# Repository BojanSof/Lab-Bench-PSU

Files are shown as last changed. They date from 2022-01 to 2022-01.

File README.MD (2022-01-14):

# Programmable laboratory bench power supply

Programmable laboratory bench PSU, consisting of linear regulator and switching
preregulator.

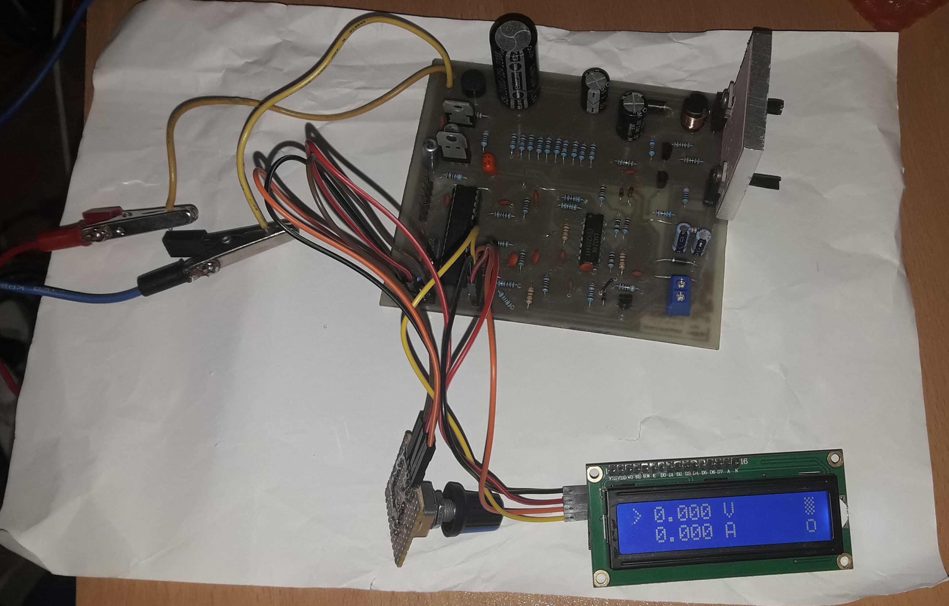
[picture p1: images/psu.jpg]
lab bench psu


## Block diagram

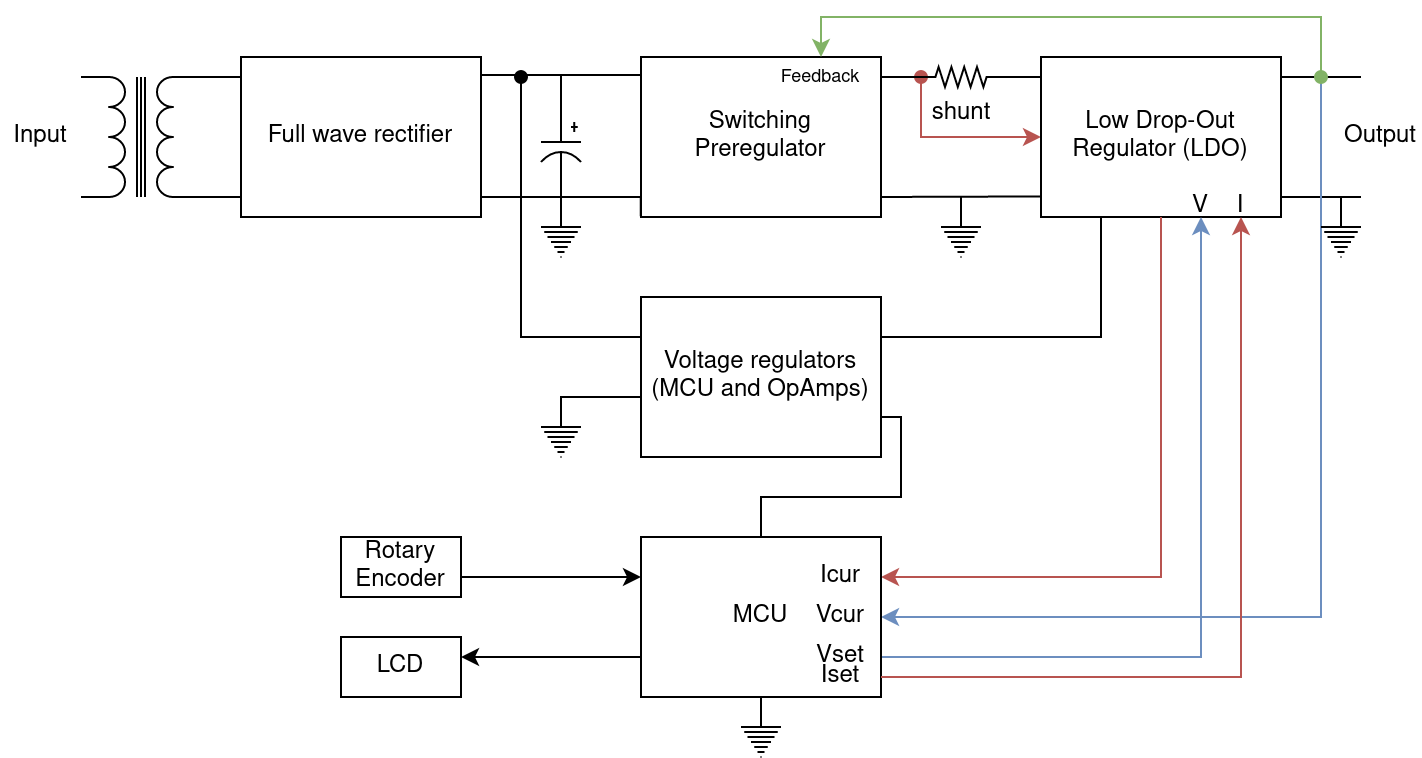
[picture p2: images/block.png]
block diagram


I used transformer just because I had it laying around.

The switching preregulator is actually buck converter realised with LM2576-ADJ
and it keeps constant 1.5 V on the LDO.

The MCU I used is PIC16F18855, which is very easily available in my country and
it is pretty cheap. It has 10-bit ADC and maximum PWM resolution of 10 bits.

The MCU samples the output, divided by 3 with voltage divider, to obtain the
output voltage value, and the output from the differential amplifier whose 
output is proportional to the voltage of the shunt resistor.

The LDO is realised with TIP41 pass transistor and LM324 operational amplifier
among the main components.

The LCD is 2 rows by 16 columns, with HD44780 controller and the interface to 
the MCU is done via I2C I/O expander (PCF8574).

## Goal specifications

Voltage: 0 - 15 V, with steps of 15 mV
Current: 0 - 1 A, with steps of 5 mA

Additional software modifications and testing is required to meet these 
specifications, especially the current limit one.

## PCB and schematic

The schematic and PCB design is created in KiCad.

The PCB is single layer because I made it in my home. I only used THT
components for the whole design.

## Firmware

The firmware is developed using MPLAB X IDE, with the free version of the XC8 
compiler.

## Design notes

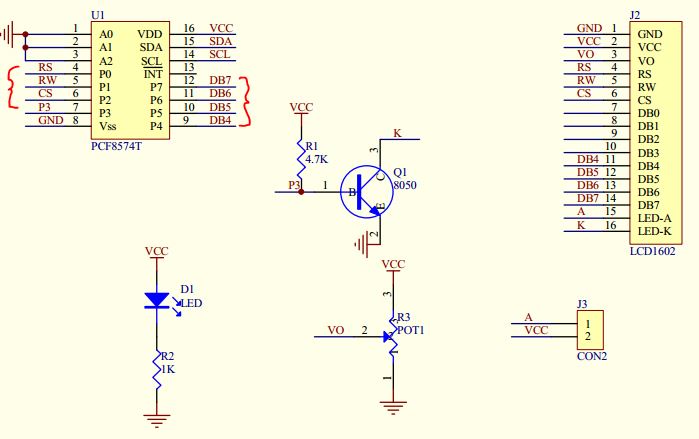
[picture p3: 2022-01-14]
datasheets/lcd_i2c.jpg

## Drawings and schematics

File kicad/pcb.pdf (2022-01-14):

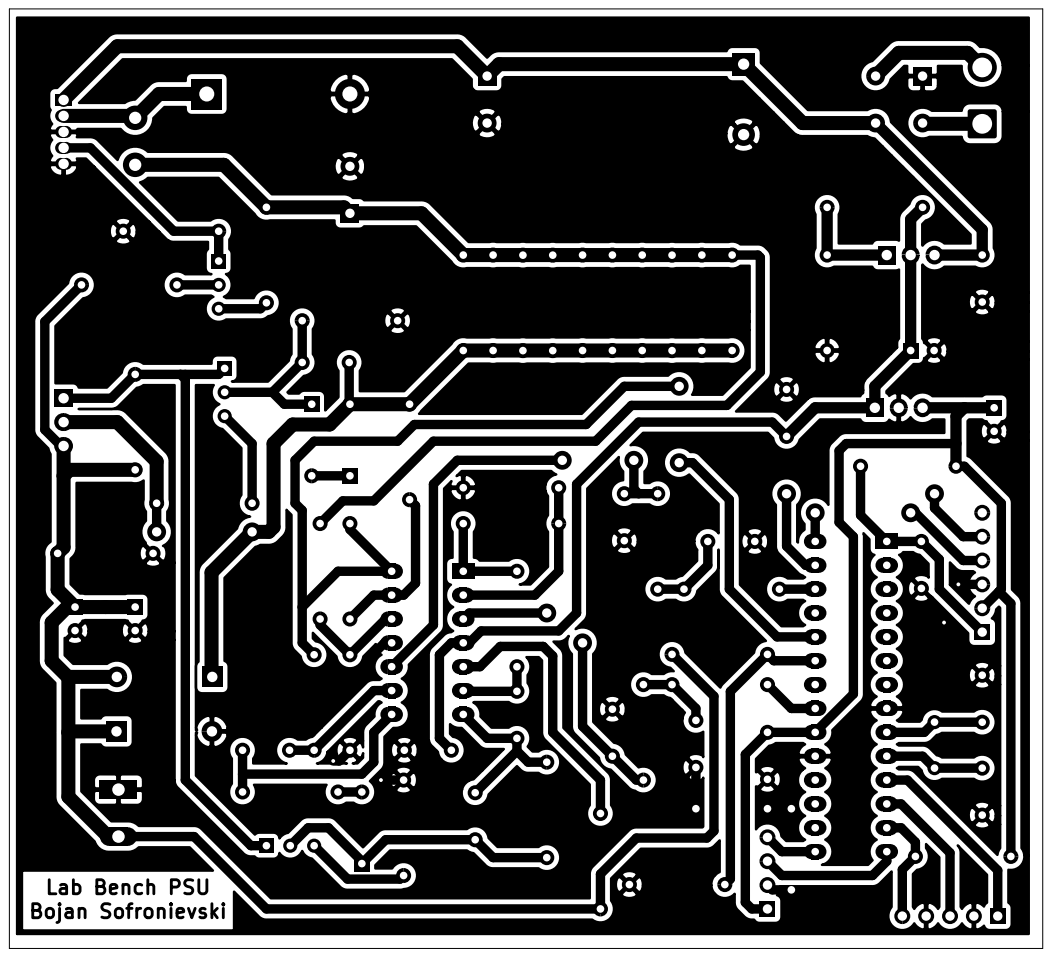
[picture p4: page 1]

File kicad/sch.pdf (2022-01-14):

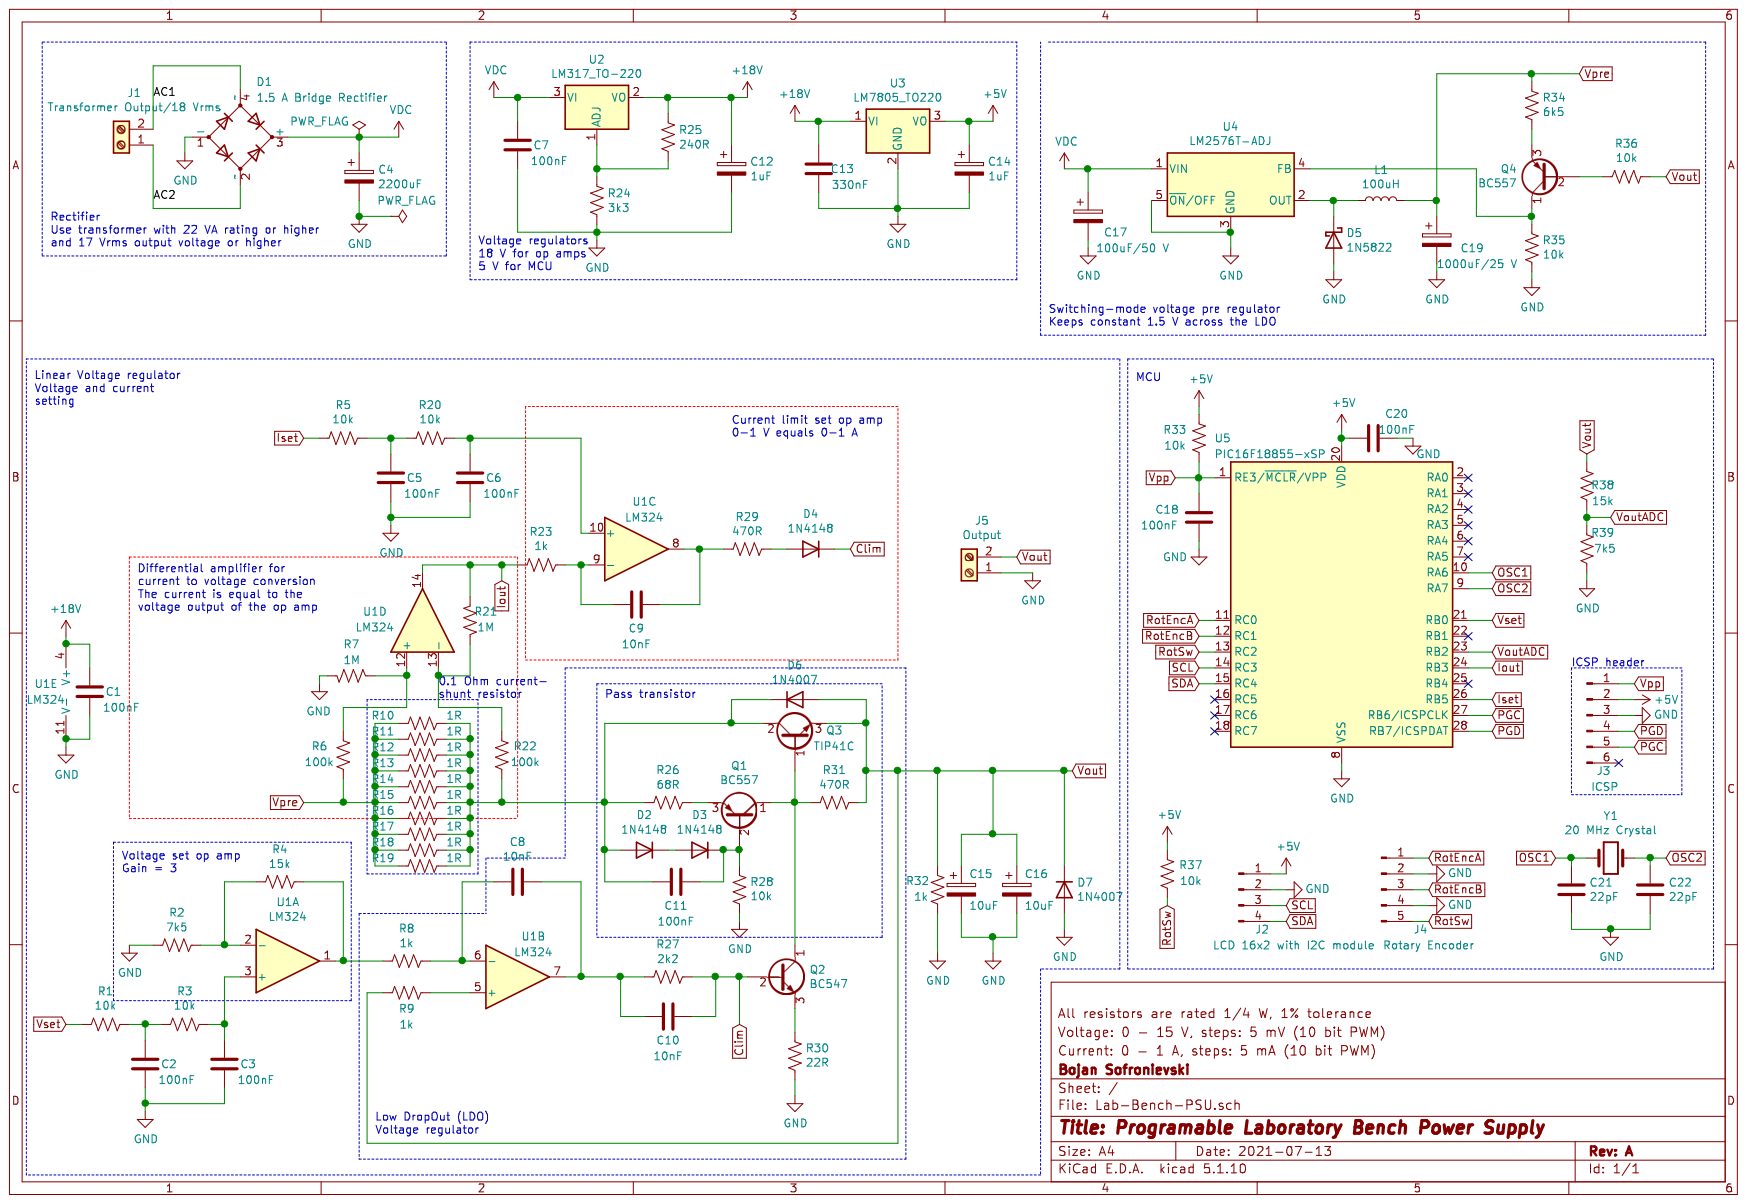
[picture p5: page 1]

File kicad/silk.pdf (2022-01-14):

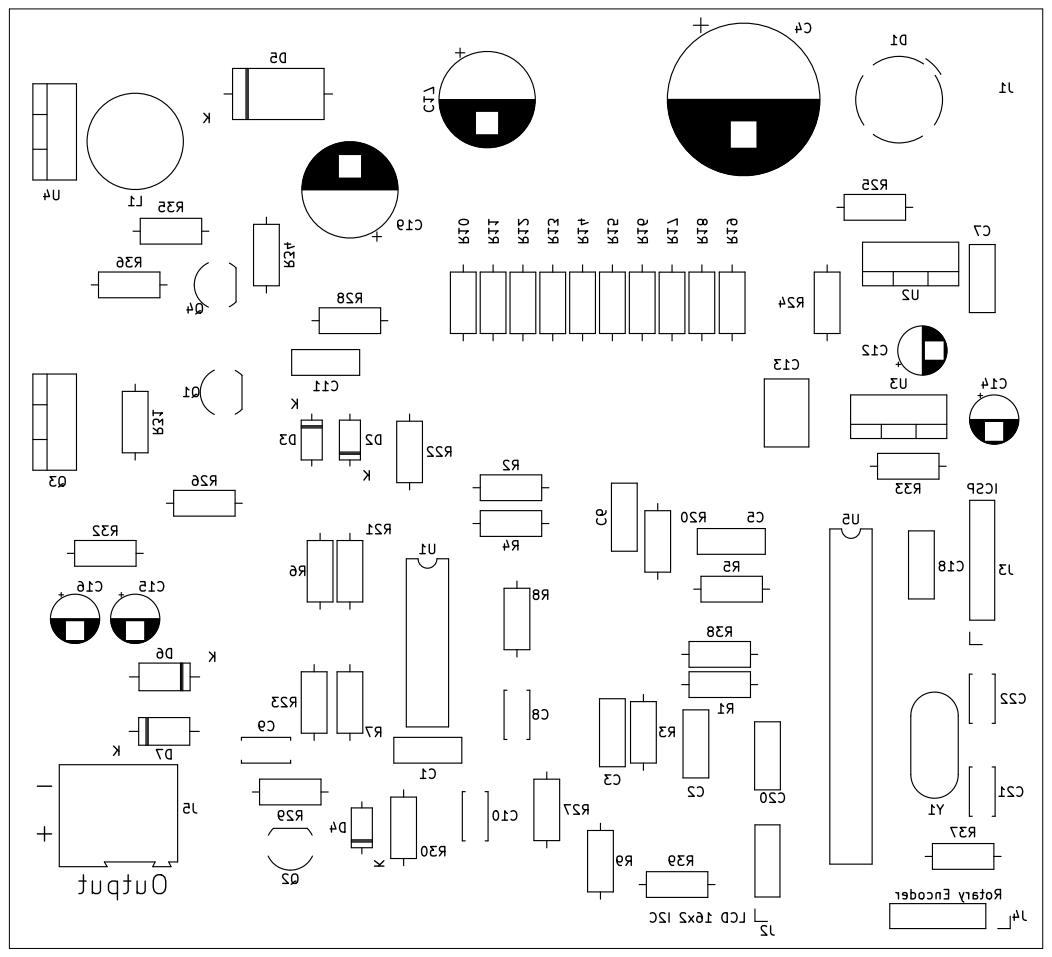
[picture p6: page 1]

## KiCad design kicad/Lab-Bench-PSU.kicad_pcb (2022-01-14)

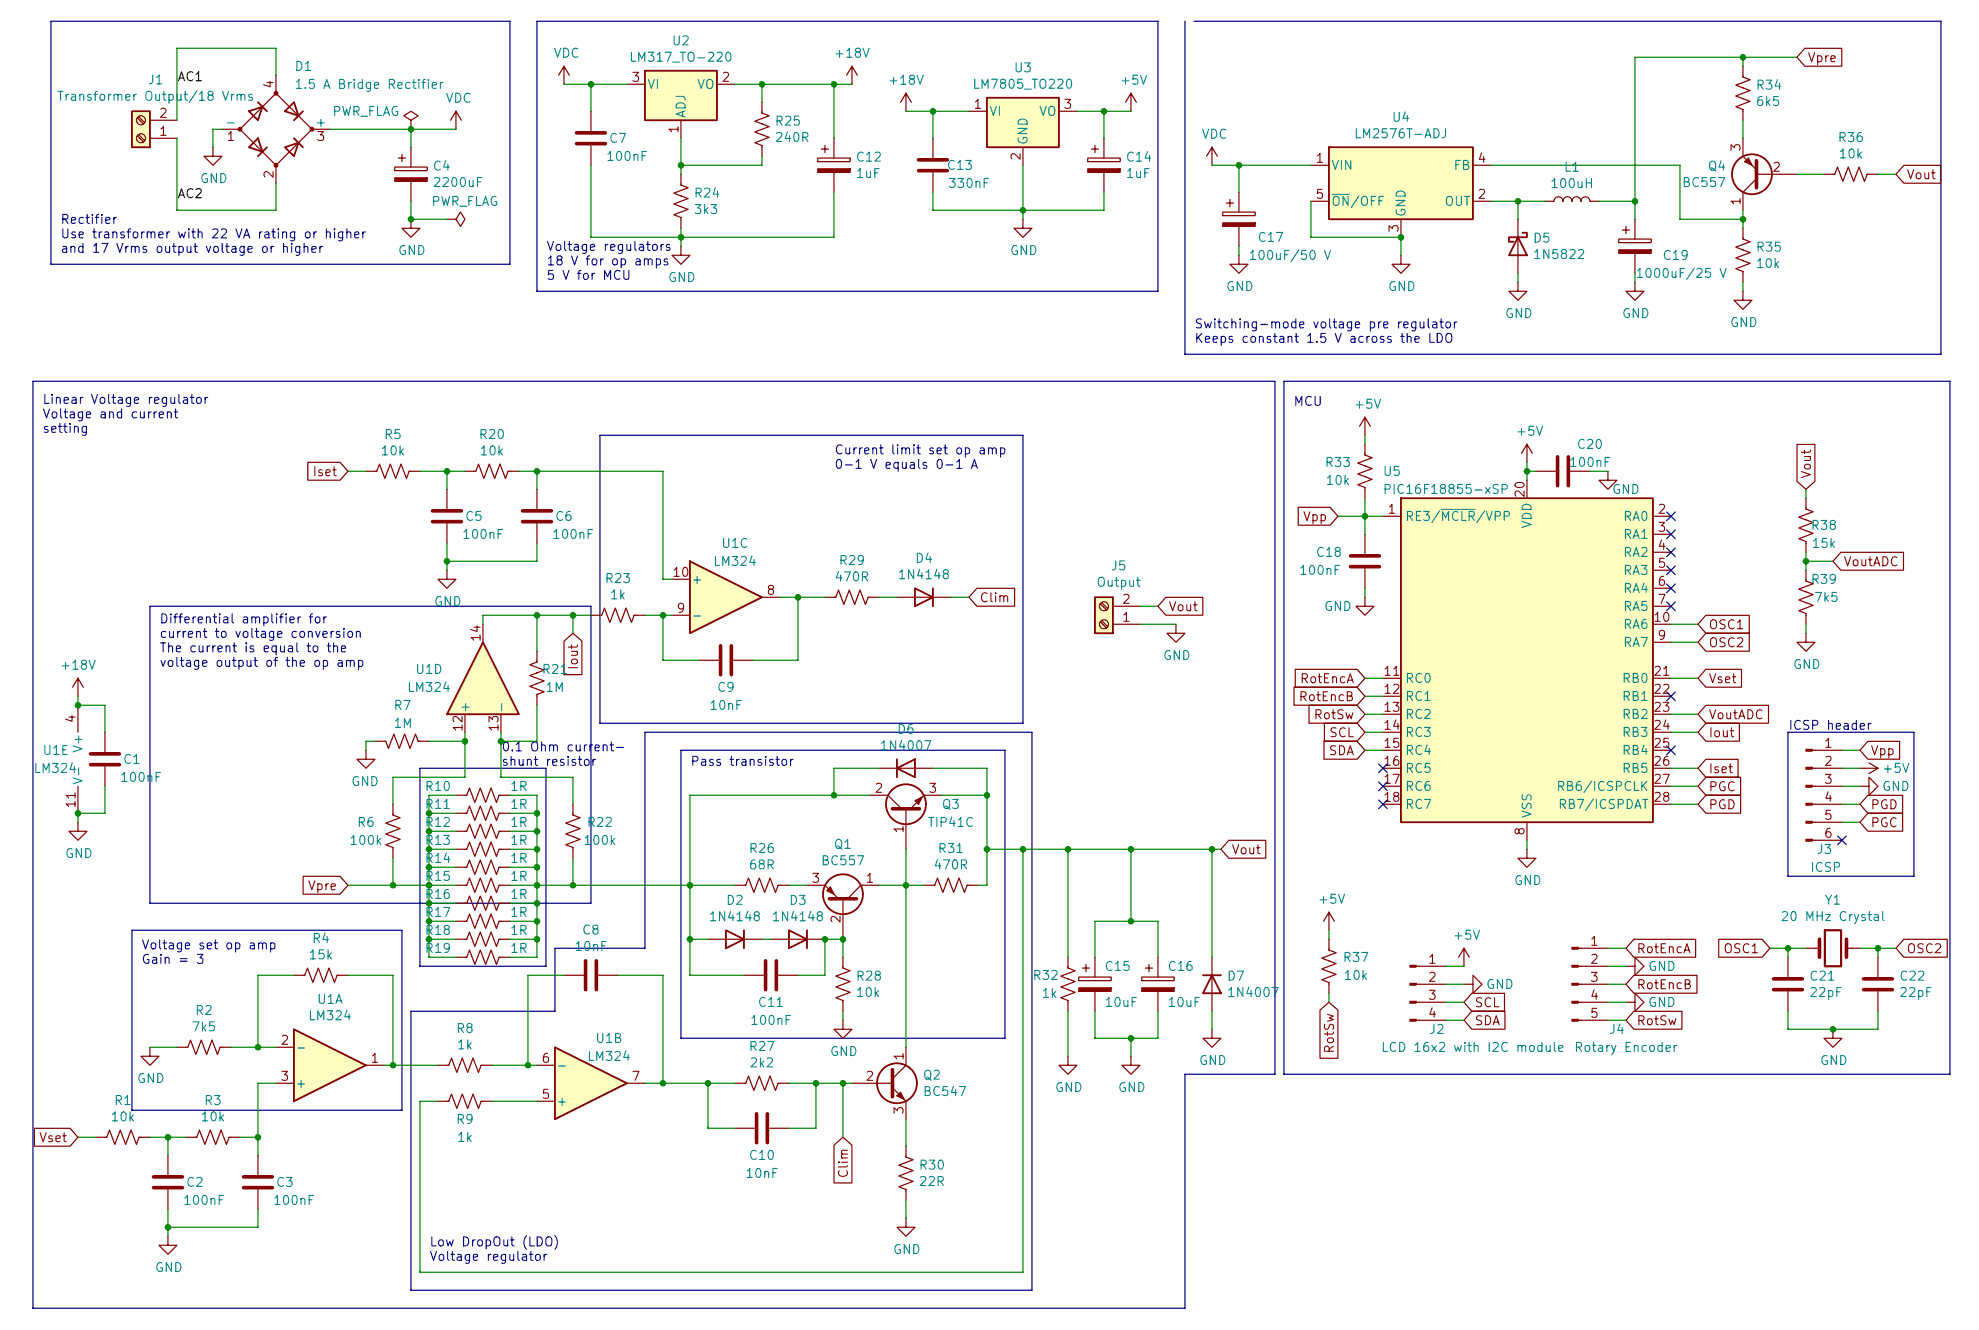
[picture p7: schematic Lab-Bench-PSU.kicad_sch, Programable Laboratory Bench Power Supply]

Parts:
C1, C2, C3, C5, C6, C7, C11, C18, C20: 100nF; C_Rect_L7.0mm_W2.5mm_P5.00mm
C4: 2200uF; CP_Radial_D16.0mm_P7.50mm
C8, C9, C10: 10nF; C_Disc_D5.0mm_W2.5mm_P5.00mm
C12, C14: 1uF; CP_Radial_D5.0mm_P2.50mm
C13: 330nF; C_Rect_L7.0mm_W4.5mm_P5.00mm
C15, C16: 10uF; CP_Radial_D5.0mm_P2.50mm
C17: 100uF/50 V; CP_Radial_D10.0mm_P5.00mm
C19: 1000uF/25 V; CP_Radial_D10.0mm_P5.00mm
C21, C22: 22pF; C_Disc_D5.0mm_W2.5mm_P5.00mm
D1: 1.5 A Bridge Rectifier; Diode_Bridge_Round_D9.0mm
D2, D3, D4: 1N4148; D_DO-35_SOD27_P7.62mm_Horizontal
D5: 1N5822; D_DO-201AD_P15.24mm_Horizontal
D6, D7: 1N4007; D_DO-41_SOD81_P10.16mm_Horizontal
J1: Transformer Output/18 Vrms; SolderWire-1.5sqmm_1x02_P6mm_D1.7mm_OD3mm
J2: LCD 16x2 with I2C module; PinHeader_1x04_P2.54mm_Vertical
J3: ICSP; PinHeader_1x06_P2.54mm_Vertical
J4: Rotary Encoder; PinHeader_1x05_P2.54mm_Vertical
J5: Output; TerminalBlock_Altech_AK300-2_P5.00mm
L1: 100uH; L_Radial_D10.0mm_P5.00mm_Fastron_07M
Q1, Q4: BC557; TO-92_Inline_Wide
Q2: BC547; TO-92_Inline_Wide
Q3: TIP41C; TO-220-3_Vertical
R1, R3, R5, R20, R28, R33, R35, R36, R37: 10k; R_Axial_DIN0207_L6.3mm_D2.5mm_P10.16mm_Horizontal
R2, R39: 7k5; R_Axial_DIN0207_L6.3mm_D2.5mm_P10.16mm_Horizontal
R4, R38: 15k; R_Axial_DIN0207_L6.3mm_D2.5mm_P10.16mm_Horizontal
R6, R22: 100k; R_Axial_DIN0207_L6.3mm_D2.5mm_P10.16mm_Horizontal
R7, R21: 1M; R_Axial_DIN0207_L6.3mm_D2.5mm_P10.16mm_Horizontal
R8, R9, R23, R32: 1k; R_Axial_DIN0207_L6.3mm_D2.5mm_P10.16mm_Horizontal
R10, R11, R12, R13, R14, R15, R16, R17, R18, R19: 1R; R_Axial_DIN0207_L6.3mm_D2.5mm_P10.16mm_Horizontal
R24: 3k3; R_Axial_DIN0207_L6.3mm_D2.5mm_P10.16mm_Horizontal
R25: 240R; R_Axial_DIN0207_L6.3mm_D2.5mm_P10.16mm_Horizontal
R26: 68R; R_Axial_DIN0207_L6.3mm_D2.5mm_P10.16mm_Horizontal
R27: 2k2; R_Axial_DIN0207_L6.3mm_D2.5mm_P10.16mm_Horizontal
R29, R31: 470R; R_Axial_DIN0207_L6.3mm_D2.5mm_P10.16mm_Horizontal
R30: 22R; R_Axial_DIN0207_L6.3mm_D2.5mm_P10.16mm_Horizontal
R34: 6k5; R_Axial_DIN0207_L6.3mm_D2.5mm_P10.16mm_Horizontal
U1: LM324; DIP-14_W7.62mm_LongPads
U2: LM317_TO-220; TO-220-3_Vertical
U3: LM7805_TO220; TO-220-3_Vertical
U4: LM2576T-ADJ; TO-220-5_Vertical
U5: PIC16F18855-xSP; DIP-28_W7.62mm_LongPads
Y1: 20 MHz Crystal; Crystal_HC18-U_Vertical

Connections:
+5V: C14.1, C20.1, J2.1, J3.2, R33.2, R37.2, U3.3 (VO), U5.20 (VDD)
+18V: C1.1, C12.1, C13.1, R25.1, U1.4 (V+), U2.2 (VO), U3.1 (VI)
/AC1: D1.4, J1.2
/AC2: D1.2, J1.1
Clim: C10.1, D4.1 (K), Q2.2 (B), R27.1
GND: C1.2, C2.2, C3.2, C4.2, C5.2, C6.2, C7.2, C12.2, C13.2, C14.2, C15.2, C16.2, C17.2, C18.2, C19.2, C20.2, C21.2, C22.2, D1.1 (-), D5.2 (A), D7.2 (A), J2.2, J3.3, J4.2, J4.4, J5.1, R2.2, R7.1, R24.2, R28.1, R30.1, R32.1, R35.1, R39.1, U1.11 (V-), U3.2 (GND), U4.3 (GND), U4.5 (~ON/OFF), U5.8 (VSS), U5.19 (VSS)
Iout: R21.2, R23.1, U1.14, U5.24 (RB3)
Iset: R5.1, U5.26 (RB5)
unnamed: C2.1, R1.2, R3.1
unnamed: C3.1, R3.2, U1.3 (+)
unnamed: C5.1, R5.2, R20.1
unnamed: C6.1, R20.2, U1.10 (+)
unnamed: C8.2, R8.1, U1.6 (-)
unnamed: C9.1, R29.2, U1.8
unnamed: C9.2, R23.2, U1.9 (-)
unnamed: C8.1, C10.2, R27.2, U1.7
unnamed: C11.1, D3.1 (K), Q1.2 (B), R28.2
unnamed: C11.2, D2.2 (A), D6.1 (K), Q3.2 (C), R10.1, R11.1, R12.1, R13.1, R14.1, R15.1, R16.1, R17.1, R18.1, R19.1, R22.1, R26.2
unnamed: D2.1 (K), D3.2 (A)
unnamed: D4.2 (A), R29.1
unnamed: D5.1 (K), L1.1, U4.2 (OUT)
unnamed: Q1.1 (C), Q2.1 (C), Q3.1 (B), R31.2
unnamed: Q1.3 (E), R26.1
unnamed: Q2.3 (E), R30.2
unnamed: Q4.1 (C), R35.2, U4.4 (FB)
unnamed: Q4.2 (B), R36.1
unnamed: Q4.3 (E), R34.1
unnamed: R2.1, R4.2, U1.2 (-)
unnamed: R4.1, R8.2, U1.1
unnamed: R6.2, R7.2, U1.12 (+)
unnamed: R9.1, U1.5 (+)
unnamed: R21.1, R22.2, U1.13 (-)
unnamed: R24.1, R25.2, U2.1 (ADJ)
OSC1: C21.1, U5.10 (RA6), Y1.1
OSC2: C22.1, U5.9 (RA7), Y1.2
PGC: J3.5, U5.27 (RB6/ICSPCLK)
PGD: J3.4, U5.28 (RB7/ICSPDAT)
RotEncA: J4.1, U5.11 (RC0)
RotEncB: J4.3, U5.12 (RC1)
RotSw: J4.5, R37.1, U5.13 (RC2)
SCL: J2.3, U5.14 (RC3)
SDA: J2.4, U5.15 (RC4)
VDC: C4.1, C7.1, C17.1, D1.3 (+), U2.3 (VI), U4.1 (VIN)
Vout: C15.1, C16.1, D6.2 (A), D7.1 (K), J5.2, Q3.3 (E), R9.2, R31.1, R32.2, R36.2, R38.2
VoutADC: R38.1, R39.2, U5.23 (RB2)
Vpp: C18.1, J3.1, R33.1, U5.1 (RE3/~MCLR/VPP)
Vpre: C19.1, L1.2, R6.1, R10.2, R11.2, R12.2, R13.2, R14.2, R15.2, R16.2, R17.2, R18.2, R19.2, R34.2
Vset: R1.1, U5.21 (RB0)

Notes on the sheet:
ICSP header
Low DropOut (LDO) Voltage regulator
MCU
Voltage regulators 18 V for op amps 5 V for MCU
Switching-mode voltage pre regulator Keeps constant 1.5 V across the LDO
Rectifier Use transformer with 22 VA rating or higher and 17 Vrms output voltage or higher
0.1 Ohm current- shunt resistor
Pass transistor
Linear Voltage regulator Voltage and current setting
Current limit set op amp 0-1 V equals 0-1 A
Voltage set op amp Gain = 3
Differential amplifier for current to voltage conversion The current is equal to the voltage output of the op amp

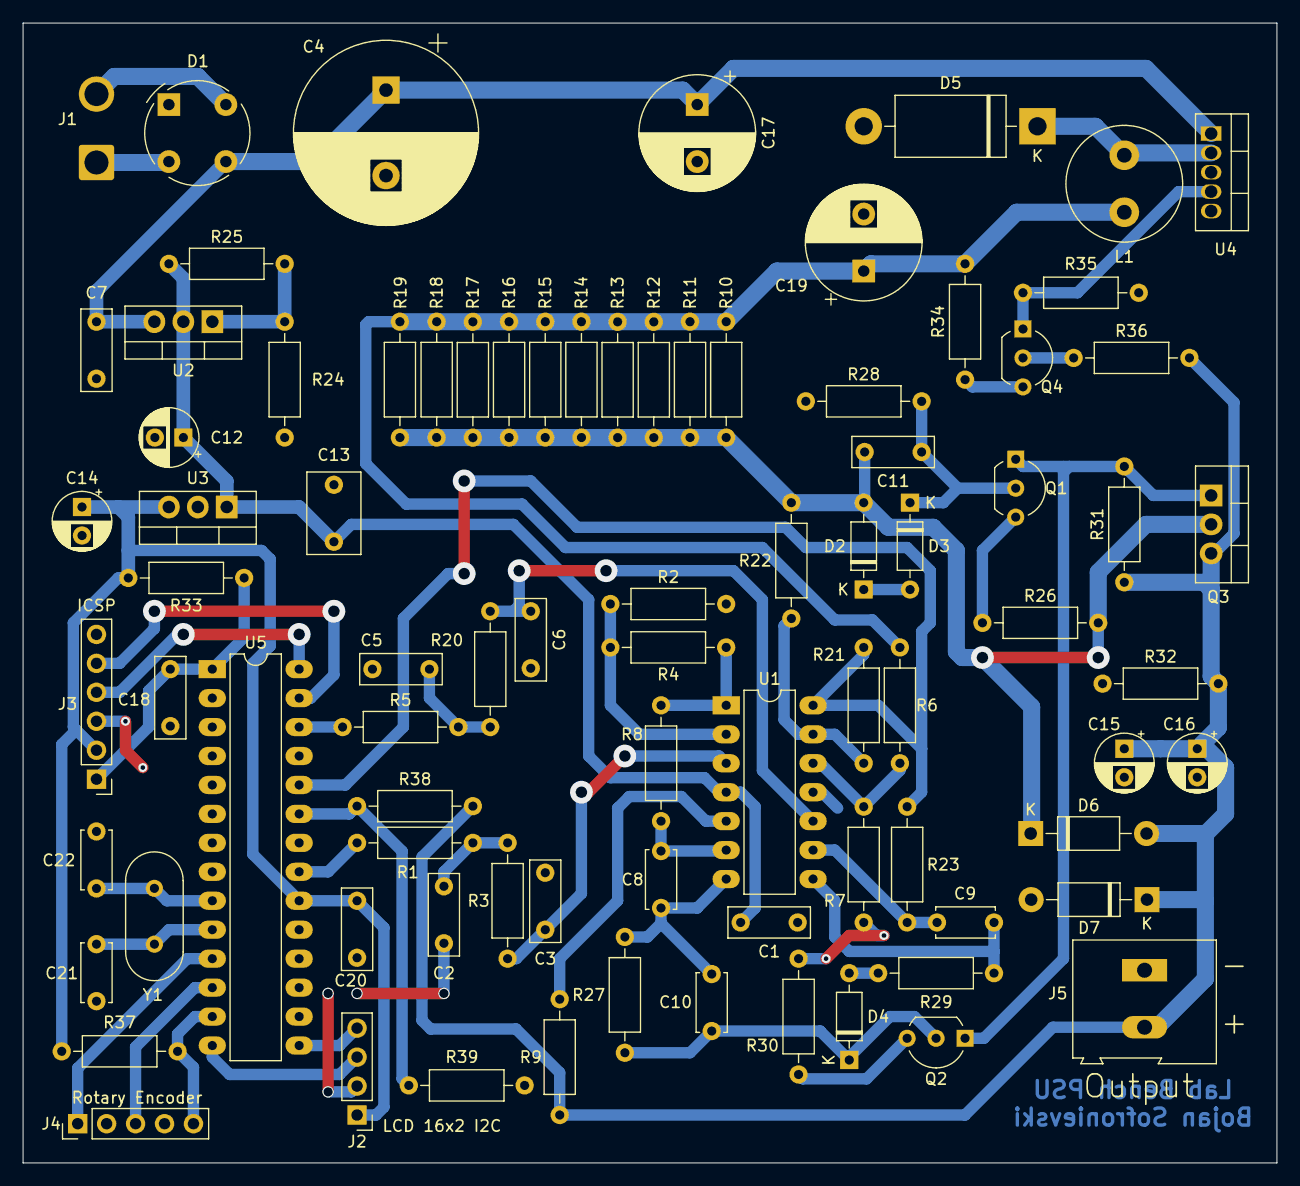
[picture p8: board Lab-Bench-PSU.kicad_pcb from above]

Board: 2 copper layers, 110.0 x 100.0 mm, 84 parts (0 on the bottom side), 48 nets.

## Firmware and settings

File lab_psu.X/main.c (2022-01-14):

/**
  Generated Main Source File

  Company:
    Microchip Technology Inc.

  File Name:
    main.c

  Summary:
    This is the main file generated using PIC10 / PIC12 / PIC16 / PIC18 MCUs

  Description:
    This header file provides implementations for driver APIs for all modules selected in the GUI.
    Generation Information :
        Product Revision  :  PIC10 / PIC12 / PIC16 / PIC18 MCUs - 1.81.7
        Device            :  PIC16F18855
        Driver Version    :  2.00
*/

/*
    (c) 2018 Microchip Technology Inc. and its subsidiaries. 
    
    Subject to your compliance with these terms, you may use Microchip software and any 
    derivatives exclusively with Microchip products. It is your responsibility to comply with third party 
    license terms applicable to your use of third party software (including open source software) that 
    may accompany Microchip software.
    
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
    IN NO EVENT WILL MICROCHIP BE LIABLE FOR ANY INDIRECT, SPECIAL, PUNITIVE, 
    INCIDENTAL OR CONSEQUENTIAL LOSS, DAMAGE, COST OR EXPENSE OF ANY KIND 
    WHATSOEVER RELATED TO THE SOFTWARE, HOWEVER CAUSED, EVEN IF MICROCHIP 
    HAS BEEN ADVISED OF THE POSSIBILITY OR THE DAMAGES ARE FORESEEABLE. TO 
    THE FULLEST EXTENT ALLOWED BY LAW, MICROCHIP'S TOTAL LIABILITY ON ALL 
    CLAIMS IN ANY WAY RELATED TO THIS SOFTWARE WILL NOT EXCEED THE AMOUNT 
    OF FEES, IF ANY, THAT YOU HAVE PAID DIRECTLY TO MICROCHIP FOR THIS 
    SOFTWARE.
*/

#pragma warning disable 520

#include "mcc_generated_files/mcc.h"
#include "psu.h"
#include "utility.h"

// Utility global variables
volatile uint8_t change = 0;

// LCD instance
#define LCD_ADDR 0x27
LCD lcd;

// PSU instance
volatile PSU psu;

// TMR1 ISR
void regularUpdate(void) {
    static uint16_t count = 0;  // when to update the measurements
    // check if the measurements should be updated
    count++;
    if(count == 300) {
        if(psu.state > STATE_OFF_BOUND)
            change = MEASUREMENTS_CHANGE;
        count = 0;
    }
    // check the button
    RotaryEncoder_button();
}

/*
                         Main application
 */
void main(void)
{
    // initialize the device
    SYSTEM_Initialize();
    
    // Initialize the PSU
    PSU_init(&psu, &lcd, LCD_ADDR, 15000, 1000); // 15 V max voltage and 1 A max current
    
    // TMR1 ISR, for updating the measurements and button debouncing
    TMR1_SetInterruptHandler(regularUpdate);
    
    // When using interrupts, you need to set the Global and Peripheral Interrupt Enable bits
    // Use the following macros to:

    // Enable the Global Interrupts
    INTERRUPT_GlobalInterruptEnable();

    // Enable the Peripheral Interrupts
    INTERRUPT_PeripheralInterruptEnable();

    // Disable the Global Interrupts
    //INTERRUPT_GlobalInterruptDisable();

    // Disable the Peripheral Interrupts
    //INTERRUPT_PeripheralInterruptDisable();

    while (1)
    {
        PSU_update(&psu, RotaryEncoder_read());
    }
}
/**
 End of File
*/

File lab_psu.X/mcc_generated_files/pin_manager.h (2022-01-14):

/**
  @Generated Pin Manager Header File

  @Company:
    Microchip Technology Inc.

  @File Name:
    pin_manager.h

  @Summary:
    This is the Pin Manager file generated using PIC10 / PIC12 / PIC16 / PIC18 MCUs

  @Description
    This header file provides APIs for driver for .
    Generation Information :
        Product Revision  :  PIC10 / PIC12 / PIC16 / PIC18 MCUs - 1.81.7
        Device            :  PIC16F18855
        Driver Version    :  2.11
    The generated drivers are tested against the following:
        Compiler          :  XC8 2.31 and above
        MPLAB 	          :  MPLAB X 5.45	
*/

/*
    (c) 2018 Microchip Technology Inc. and its subsidiaries. 
    
    Subject to your compliance with these terms, you may use Microchip software and any 
    derivatives exclusively with Microchip products. It is your responsibility to comply with third party 
    license terms applicable to your use of third party software (including open source software) that 
    may accompany Microchip software.
    
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
    IN NO EVENT WILL MICROCHIP BE LIABLE FOR ANY INDIRECT, SPECIAL, PUNITIVE, 
    INCIDENTAL OR CONSEQUENTIAL LOSS, DAMAGE, COST OR EXPENSE OF ANY KIND 
    WHATSOEVER RELATED TO THE SOFTWARE, HOWEVER CAUSED, EVEN IF MICROCHIP 
    HAS BEEN ADVISED OF THE POSSIBILITY OR THE DAMAGES ARE FORESEEABLE. TO 
    THE FULLEST EXTENT ALLOWED BY LAW, MICROCHIP'S TOTAL LIABILITY ON ALL 
    CLAIMS IN ANY WAY RELATED TO THIS SOFTWARE WILL NOT EXCEED THE AMOUNT 
    OF FEES, IF ANY, THAT YOU HAVE PAID DIRECTLY TO MICROCHIP FOR THIS 
    SOFTWARE.
*/

#ifndef PIN_MANAGER_H
#define PIN_MANAGER_H

/**
  Section: Included Files
*/

#include <xc.h>

#define INPUT   1
#define OUTPUT  0

#define HIGH    1
#define LOW     0

#define ANALOG      1
#define DIGITAL     0

#define PULL_UP_ENABLED      1
#define PULL_UP_DISABLED     0

// get/set RB0 procedures
#define RB0_SetHigh()            do { LATBbits.LATB0 = 1; } while(0)
#define RB0_SetLow()             do { LATBbits.LATB0 = 0; } while(0)
#define RB0_Toggle()             do { LATBbits.LATB0 = ~LATBbits.LATB0; } while(0)
#define RB0_GetValue()              PORTBbits.RB0
#define RB0_SetDigitalInput()    do { TRISBbits.TRISB0 = 1; } while(0)
#define RB0_SetDigitalOutput()   do { TRISBbits.TRISB0 = 0; } while(0)
#define RB0_SetPullup()             do { WPUBbits.WPUB0 = 1; } while(0)
#define RB0_ResetPullup()           do { WPUBbits.WPUB0 = 0; } while(0)
#define RB0_SetAnalogMode()         do { ANSELBbits.ANSB0 = 1; } while(0)
#define RB0_SetDigitalMode()        do { ANSELBbits.ANSB0 = 0; } while(0)

// get/set Vout aliases
#define Vout_TRIS                 TRISBbits.TRISB2
#define Vout_LAT                  LATBbits.LATB2
#define Vout_PORT                 PORTBbits.RB2
#define Vout_WPU                  WPUBbits.WPUB2
#define Vout_OD                   ODCONBbits.ODCB2
#define Vout_ANS                  ANSELBbits.ANSB2
#define Vout_SetHigh()            do { LATBbits.LATB2 = 1; } while(0)
#define Vout_SetLow()             do { LATBbits.LATB2 = 0; } while(0)
#define Vout_Toggle()             do { LATBbits.LATB2 = ~LATBbits.LATB2; } while(0)
#define Vout_GetValue()           PORTBbits.RB2
#define Vout_SetDigitalInput()    do { TRISBbits.TRISB2 = 1; } while(0)
#define Vout_SetDigitalOutput()   do { TRISBbits.TRISB2 = 0; } while(0)
#define Vout_SetPullup()          do { WPUBbits.WPUB2 = 1; } while(0)
#define Vout_ResetPullup()        do { WPUBbits.WPUB2 = 0; } while(0)
#define Vout_SetPushPull()        do { ODCONBbits.ODCB2 = 0; } while(0)
#define Vout_SetOpenDrain()       do { ODCONBbits.ODCB2 = 1; } while(0)
#define Vout_SetAnalogMode()      do { ANSELBbits.ANSB2 = 1; } while(0)
#define Vout_SetDigitalMode()     do { ANSELBbits.ANSB2 = 0; } while(0)

// get/set Iout aliases
#define Iout_TRIS                 TRISBbits.TRISB3
#define Iout_LAT                  LATBbits.LATB3
#define Iout_PORT                 PORTBbits.RB3
#define Iout_WPU                  WPUBbits.WPUB3
#define Iout_OD                   ODCONBbits.ODCB3
#define Iout_ANS                  ANSELBbits.ANSB3
#define Iout_SetHigh()            do { LATBbits.LATB3 = 1; } while(0)
#define Iout_SetLow()             do { LATBbits.LATB3 = 0; } while(0)
#define Iout_Toggle()             do { LATBbits.LATB3 = ~LATBbits.LATB3; } while(0)
#define Iout_GetValue()           PORTBbits.RB3
#define Iout_SetDigitalInput()    do { TRISBbits.TRISB3 = 1; } while(0)
#define Iout_SetDigitalOutput()   do { TRISBbits.TRISB3 = 0; } while(0)
#define Iout_SetPullup()          do { WPUBbits.WPUB3 = 1; } while(0)
#define Iout_ResetPullup()        do { WPUBbits.WPUB3 = 0; } while(0)
#define Iout_SetPushPull()        do { ODCONBbits.ODCB3 = 0; } while(0)
#define Iout_SetOpenDrain()       do { ODCONBbits.ODCB3 = 1; } while(0)
#define Iout_SetAnalogMode()      do { ANSELBbits.ANSB3 = 1; } while(0)
#define Iout_SetDigitalMode()     do { ANSELBbits.ANSB3 = 0; } while(0)

// get/set RB5 procedures
#define RB5_SetHigh()            do { LATBbits.LATB5 = 1; } while(0)
#define RB5_SetLow()             do { LATBbits.LATB5 = 0; } while(0)
#define RB5_Toggle()             do { LATBbits.LATB5 = ~LATBbits.LATB5; } while(0)
#define RB5_GetValue()              PORTBbits.RB5
#define RB5_SetDigitalInput()    do { TRISBbits.TRISB5 = 1; } while(0)
#define RB5_SetDigitalOutput()   do { TRISBbits.TRISB5 = 0; } while(0)
#define RB5_SetPullup()             do { WPUBbits.WPUB5 = 1; } while(0)
#define RB5_ResetPullup()           do { WPUBbits.WPUB5 = 0; } while(0)
#define RB5_SetAnalogMode()         do { ANSELBbits.ANSB5 = 1; } while(0)
#define RB5_SetDigitalMode()        do { ANSELBbits.ANSB5 = 0; } while(0)

// get/set RotEncCLK aliases
#define RotEncCLK_TRIS                 TRISCbits.TRISC0
#define RotEncCLK_LAT                  LATCbits.LATC0
#define RotEncCLK_PORT                 PORTCbits.RC0
#define RotEncCLK_WPU                  WPUCbits.WPUC0
#define RotEncCLK_OD                   ODCONCbits.ODCC0
#define RotEncCLK_ANS                  ANSELCbits.ANSC0
#define RotEncCLK_SetHigh()            do { LATCbits.LATC0 = 1; } while(0)
#define RotEncCLK_SetLow()             do { LATCbits.LATC0 = 0; } while(0)
#define RotEncCLK_Toggle()             do { LATCbits.LATC0 = ~LATCbits.LATC0; } while(0)
#define RotEncCLK_GetValue()           PORTCbits.RC0
#define RotEncCLK_SetDigitalInput()    do { TRISCbits.TRISC0 = 1; } while(0)
#define RotEncCLK_SetDigitalOutput()   do { TRISCbits.TRISC0 = 0; } while(0)
#define RotEncCLK_SetPullup()          do { WPUCbits.WPUC0 = 1; } while(0)
#define RotEncCLK_ResetPullup()        do { WPUCbits.WPUC0 = 0; } while(0)
#define RotEncCLK_SetPushPull()        do { ODCONCbits.ODCC0 = 0; } while(0)
#define RotEncCLK_SetOpenDrain()       do { ODCONCbits.ODCC0 = 1; } while(0)
#define RotEncCLK_SetAnalogMode()      do { ANSELCbits.ANSC0 = 1; } while(0)
#define RotEncCLK_SetDigitalMode()     do { ANSELCbits.ANSC0 = 0; } while(0)
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

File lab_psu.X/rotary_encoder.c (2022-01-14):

#include "rotary_encoder.h"
#include "mcc_generated_files/mcc.h"
#include "utility.h"

extern volatile uint8_t change;

int8_t RotaryEncoder_read(void) {
    /* The rotary encoder movements are gray coded
     * The state of the rotary encoder is represented with two bits,
     * the msb is the state of the DATA pin and the lsb is the state of the CLK
     * pin.
     * e.g. if the previous code was 0b00, for CW movement, the new code should 
     * be 0b01 and 0b10 for CCW movement; therefore, the values in the table at 
     * indices 0b0001=1 and 0b0010=2 have value 1, standing for possible state,
     * but the values at indices 0b0000=0 and 0b0011=3 have value 0, meaning
     * that the state is impossible
     *                              CCW   |   CW
     *                         <-------------------->
     * States during movement: 11<->10<->00<->01<->11
     *                                   ^^-- starting point
     */
    static uint8_t rotaryEncoderTable[] = {0,1,1,0,1,0,0,1,1,0,0,1,0,1,1,0};
    static uint8_t prevNextCode = 0; // the index for the table
    static uint16_t store = 0;       // for double (or max quadruple) debouncing
    
    prevNextCode <<= 2;
    if(RotEncCLK_GetValue()) prevNextCode |= 0x01;
    if(RotEncDT_GetValue()) prevNextCode |= 0x02;
    prevNextCode &= 0x0F;

     // If the current movement is valid, store it
     if(rotaryEncoderTable[prevNextCode] ) {
        store <<= 4;
        store |= prevNextCode;
        if ((store & 0xFF) == 0x2B) {
            change = ROTARY_ENCODER_CHANGE;
            return -1;
        }
        if ((store & 0xFF) == 0x17) {
            change = ROTARY_ENCODER_CHANGE;
            return 1;
        }
     }
     return 0;
}

void RotaryEncoder_button(void) {
    static uint16_t state = 0;
    static uint8_t pressed = 0;
    state = (state << 1) | RotEncSW_GetValue() | 0xFFF0;
    if(state == 0xFFF0) {
        if(!pressed) {
            pressed = 1;
            change = BUTTON_CHANGE;
        }
    } else {
        pressed = 0;
    }
}
